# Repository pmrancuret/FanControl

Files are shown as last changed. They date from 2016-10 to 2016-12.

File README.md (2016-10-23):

#Fan Control

*This project is still a work in progress, so the contents are incomplete*

This project contains everything needed to create a Fan Control board.  This board is used to operate two cooling fans to regulate temperature in an enclosed environment.  In our case, it is going to be used to keep a Playstation cool, inside an enclosed cabinet.  The fans are positioned over holes in the back of the cabinet.

Please feel free to contact me with questions, comments, suggestions, or contributions!

## Contents
* [Features and Specifications] (#features)
* [Parts List] (#partslist)
* [Operation Manual] (#operation)
* [Software Load Instructions] (#swload)

# <a name="features"/>Features and Specifications

## Fan Control board is used to power and control two PC fans, independently.

* Works with two standard 3-wire PC fans.
	* Pin 1 is ground.
	* Pin 2 is fan voltage.
	* Pin 3 is hall-effect sensor (for speed feedback).
* May be used with only one fan if desired.
* Continuous current rating of up to 540mA on each fan.
* Combined power rating of two fans is 6 Watts.
	* This power is limited by wall adapter power rating.
	* Using a 12V supply rated at >= 14.2 Watts would allow up to a combined fan power rating of 13 Watts.
* User may specify maximum fan voltage range.
	* Minimum fan voltage >= 3V.
	* Maximum fan voltage <= 12V.
* Speed of each fan is measured independently using hall-effect sensor feedback.
	* Minimum measurable speed of TBD rpm.
	* Maximum measurable speed of TBD rpm.
* Master On/Off switch provided at board input.

## Arduino mini used for control logic.
* An LCD screen and three pushbuttons are provided to allow the user to provide input settings and view status info.
	* Two buttons used as up/down for scrolling through menu items and adjusting values.
	* One button used as an enter key for making selections.
	* Not pressing any button for 10 seconds will return to default display screen.
* A switch is provided to turn backlight LED on/off.  
* Two potentiometers are provided to allow changing brightness and contrast of screen.
* Default display screen shows both fan speeds and both temperature readings in real-time.
* User may select displayed temperature units (C or F).
* User may change proportional and integral gains for each fan speed control loop.
* User may change various speed, voltage, and temperature limits.
* All settings saved in non-volatile EEPROM.
* User may restore all settings to default values.

## Two independent temperature sensors are used for feedback.  
* User can populate these sensors on-board, or use jumper wires to place them remotely.
* User may select whether to use an average or max temperature for determining fan speeds, or control each fan speed independently using respective temperature sensors.
* User may specify up to 8 point pairs each of the two fan speed vs. temperature lookup tables.
	* Min/Max speed values same as min/max measurable speeds listed above.
	* Minimum temperature value of 0 C.
	* Maximum temperature value of 100 C.
	* Sensor accuracy of +/- 2 C.
	* User may specify table settings with resolution of 0.1 C.
	
## Custom designed PCB.
* Dimensions are 3.1" x 3.9".
* Thickness is 0.062".
* Two-layer board, with only through-hole components for easier soldering (depending who you ask).
* Four mounting holes (0.126" drill) provided in corners.
* Refer to [The Eagle Schematic and Board Files] (https://github.com/pmrancuret/FanControl/tree/master/Schematic_and_Board) for board layout and mounting pattern.

## Custom software.
* Refer to (TBD Code Directory) for code.
* Eclipse (TBD version) used to write and compile software.
* Refer to [Software Load Instructions] (#swload) for instructions on building and loading software into the Arduino mini.

# <a name="partslist"/>Parts List

The following parts were used to assemble this board.  Please refer to [The Eagle Schematic and Board Files] (https://github.com/pmrancuret/FanControl/tree/master/Schematic_and_Board) for information about where each component is used.

Prices in table below are as of Aug 13, 2016.  If you are making this, you may choose to get some extras of some components.  The table below only lists the minimum quantity.  Mounting hardware not included.  PC Fans not included.  Tax/shipping not included.  Money could be saved by using a protoboard instead of making the PCB.  But what's the fun in that?

| Description | Manufacturer | Part Number | Quantity | Cost (each) | Cost (total) |
| --- | --- | --- | --- | --- | --- |
| Circuit Board | Pentalogix | [Upload Gerbers] (http://www.pentalogix.com) | 1 | $147.90 | $147.90 |
| Wall Adapter | Sparkfun | [TOL-09442] (https://www.sparkfun.com/products/9442) | 1 | $5.95 | $5.95 |
| Arduino Pro Mini 328 | Sparkfun | [DEV-11113] (https://www.sparkfun.com/products/11113) | 1 | $9.95 | $9.95 |
| LCD Screen | Xiamen Ocular | [GDM1602K] (https://www.sparkfun.com/products/709) | 1 | $15.95 | $15.95 |
| Pushbutton | Sparkfun | [COM-09190] (https://www.sparkfun.com/products/9190) | 3 | $0.50 | $1.50 |
| DC Power Jack | CUI Inc | [PJ-202A] (https://www.sparkfun.com/products/119) | 1 | $1.25 | $1.25 |
| Temperature Sensor | Analog Devices | [TMP37] (http://www.digikey.com/product-detail/en/analog-devices-inc/TMP37FT9Z/TMP37FT9Z-ND/1217626) | 2 | $1.54 | $3.08 |
| Female Break-Away Pin Headers | Sparkfun | [PRT-00115] (https://www.sparkfun.com/products/115) | 1 | $1.50 | $1.50 |
| Male Break-Away Pin headers | Sparkfun | [PRT-00116] (https://www.sparkfun.com/products/116) | 1 | $1.50 | $1.50 |
| 10kOhm, 1/6W, 5% Through-Hole Resistor | Sparkfun | [COM-11508] (https://www.sparkfun.com/products/11508) | 7 | NA | $0.95 |
| 5.1Ohm, 1/4W, 5% Through-Hole Resistor | Yageo | [CFR-25JB-52-5R1] (https://www.digikey.com/product-detail/en/yageo/CFR-25JB-52-5R1/5.1QBK-ND/2238) | 6 | $0.10 | $0.60 |
| 1kOhm, 1/6W, 5% Through-Hole Resistor | Yageo | [CFR-12JB-52-1K] (https://www.digikey.com/product-detail/en/yageo/CFR-12JB-52-1K/1.0KEBK-ND/4000) | 2 | $0.10 | $0.20 |
| 100Ohm, 1/2W Potentiometer | Bourns Inc. | [3362P-1-101LF] (https://www.digikey.com/product-detail/en/bourns-inc/3362P-1-101LF/3362P-101LF-ND/1088410) | 1 | $1.02 | $1.02 |
| 10kOhm, 1/2W Potentiometer | Bourns Inc. | [3362P-1-103LF] (https://www.digikey.com/product-detail/en/bourns-inc/3362P-1-103LF/3362P-103LF-ND/1088412) | 1 | $1.02 | $1.02 |
| 10uF, 25V Through-Hole Ceramic Capacitor | TDK Corporation | [FK16X7R1E106K] (https://www.digikey.com/product-detail/en/tdk-corporation/FK16X7R1E106K/445-8351-ND/2815281) | 7 | $0.63 | $4.41 |
| 1.5mH, 540mA Through-Hole Inductor | Abracon LLC | [AIUR-06-152K] (https://www.digikey.com/product-detail/en/abracon-llc/AIUR-06-152K/AIUR-06-152K-ND/2343620) | 2 | $0.99 | $1.98 |
| P-Channel MOSFET (30V, 650mA) | Microchip Technology | [VP3203N3-G] (https://www.digikey.com/product-detail/en/microchip-technology/VP3203N3-G/VP3203N3-G-ND/4902418) | 2 | $1.37 | $2.74 |
| NPN Transistor (40V, 200mA) | Fairchild Semiconductor | [2N3904BU] (https://www.digikey.com/product-detail/en/fairchild-semiconductor/2N3904BU/2N3904FS-ND/1413) | 2 | $0.18 | $0.36 |
| Shottky Diode (1A) | Fairchild Semiconductor | [1N5817] (https://www.digikey.com/product-detail/en/fairchild-semiconductor/1N5817/1N5817FSCT-ND/1532776) | 2 | $0.43 | $0.86 |
| 5V output DC-DC Converter (2.5W) | Recom Power | [R-78E5.0-0.5] (https://www.digikey.com/product-detail/en/recom-power/R-78E5.0-0.5/945-1648-5-ND/2834904) | 1 | $2.84 | $2.84 |
| Slide Switch | CW Industries | [GF-123-0054] (https://www.digikey.com/product-detail/en/cw-industries/GF-123-0054/CWI333-ND/4089770) | 2 | $0.93 | $1.86 |
| 3-Pin fan connector | TE Connectivity | [640456-3] (https://www.digikey.com/product-detail/en/te-connectivity-amp-connectors/640456-3/A19470-ND/259010) | 2 | $0.13 | $0.26 |
| Total Cost  | | | | | $207.68 |

# <a name="operation"/>Operation Manual

*work in progress*

# <a name="swload"/>Software Load Instructions

*work in progress*

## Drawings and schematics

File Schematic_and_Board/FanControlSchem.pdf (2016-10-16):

# U2ADB0 DB1 DB2 DB3 DB4 DB5 DB6 DB7 EKR/W

A

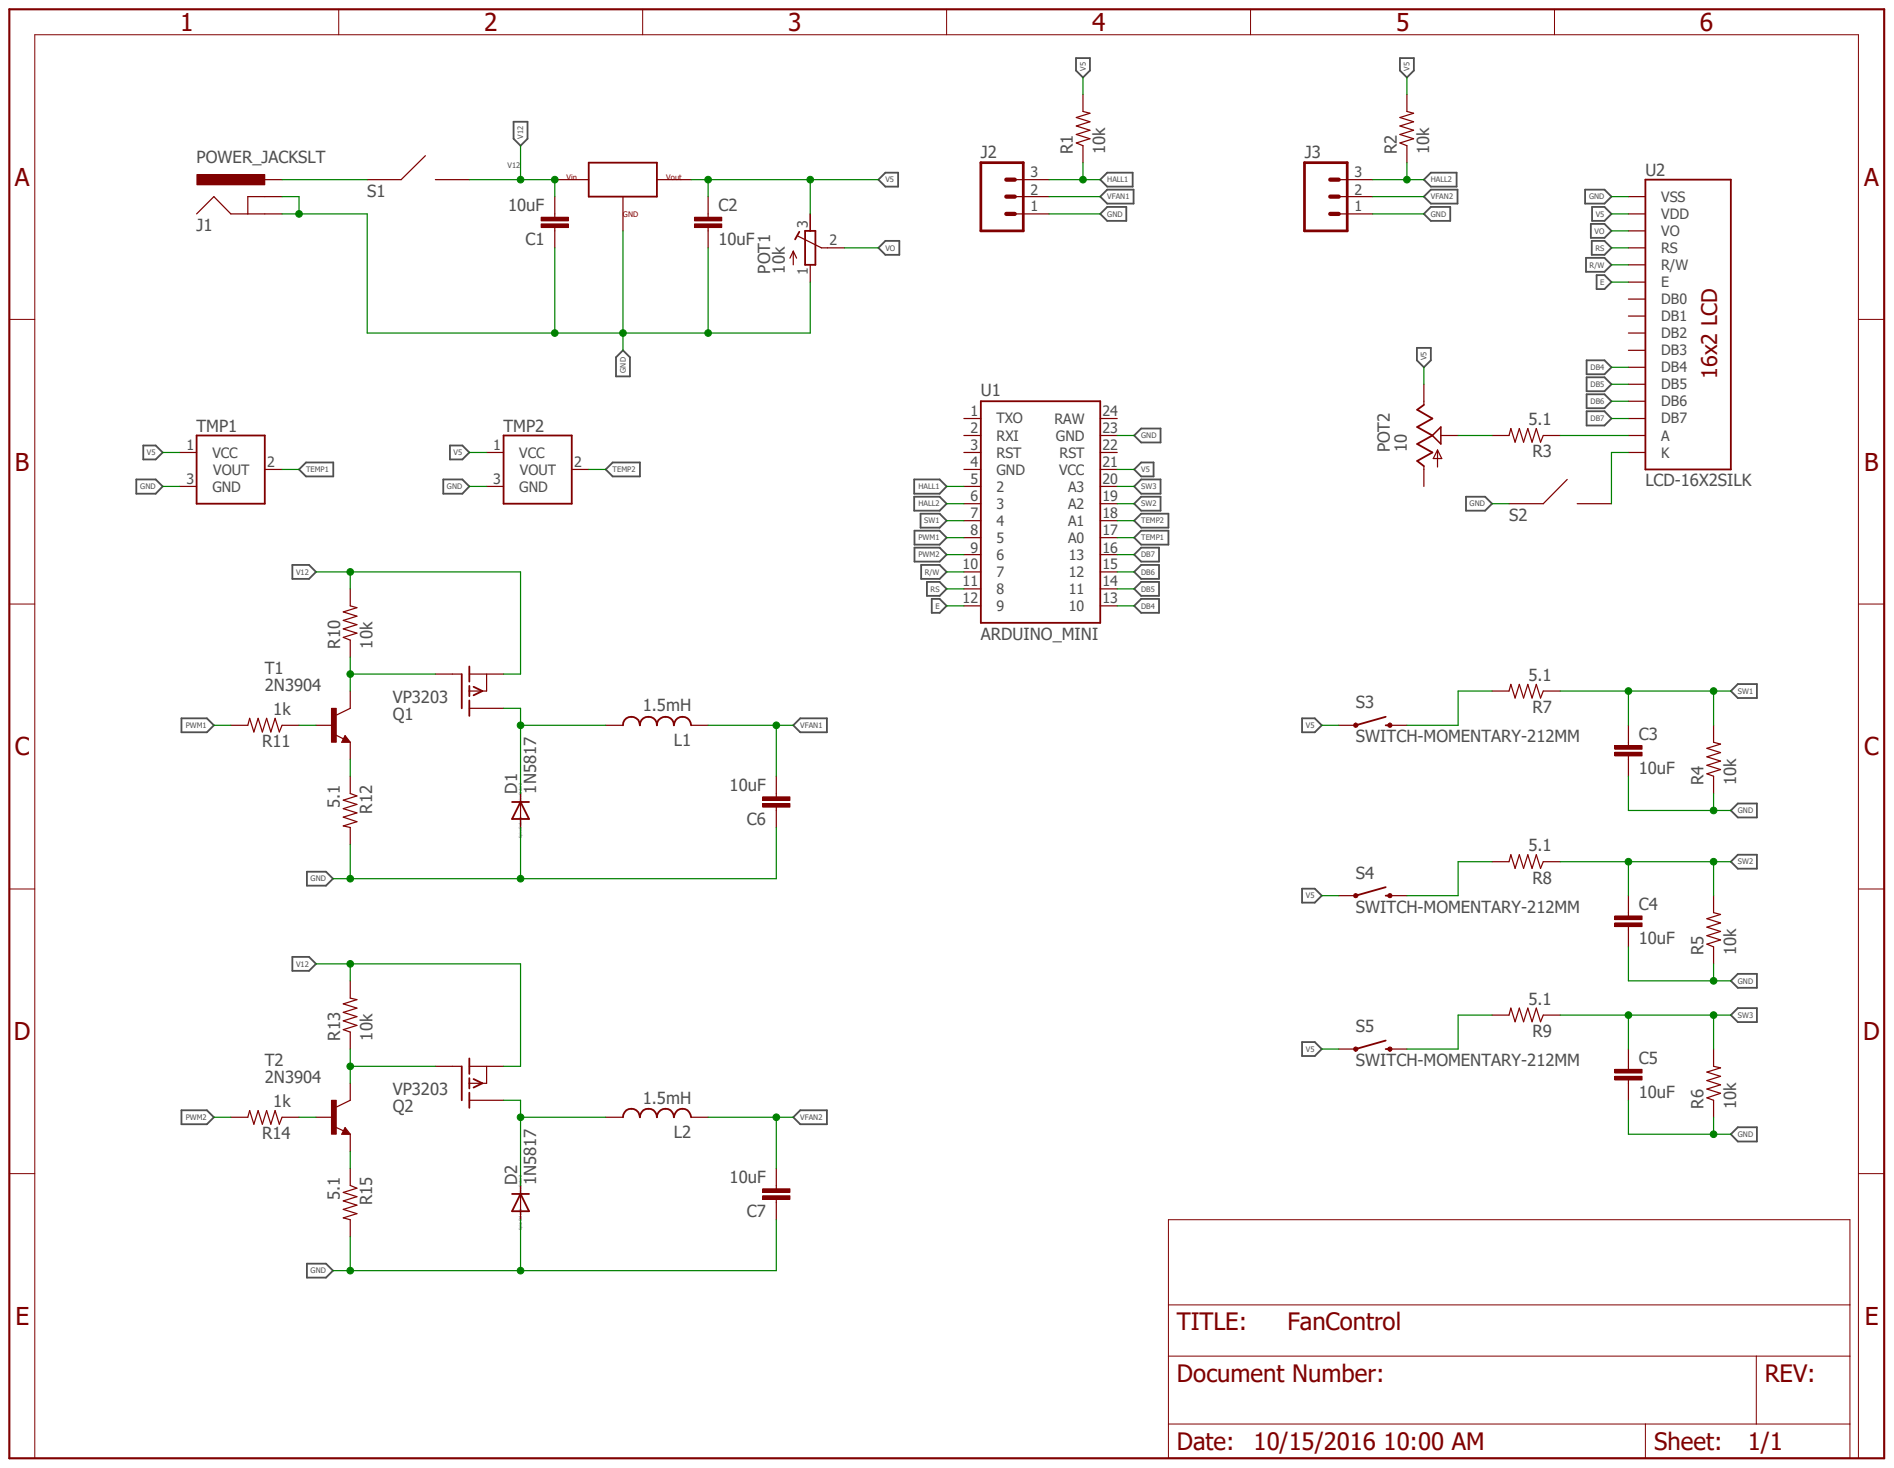
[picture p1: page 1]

SpiceOrder 1 SpiceOrder 2

Document Number: | REV:

Date: 10/15/2016 10:00 AM | Sheet: 1/1

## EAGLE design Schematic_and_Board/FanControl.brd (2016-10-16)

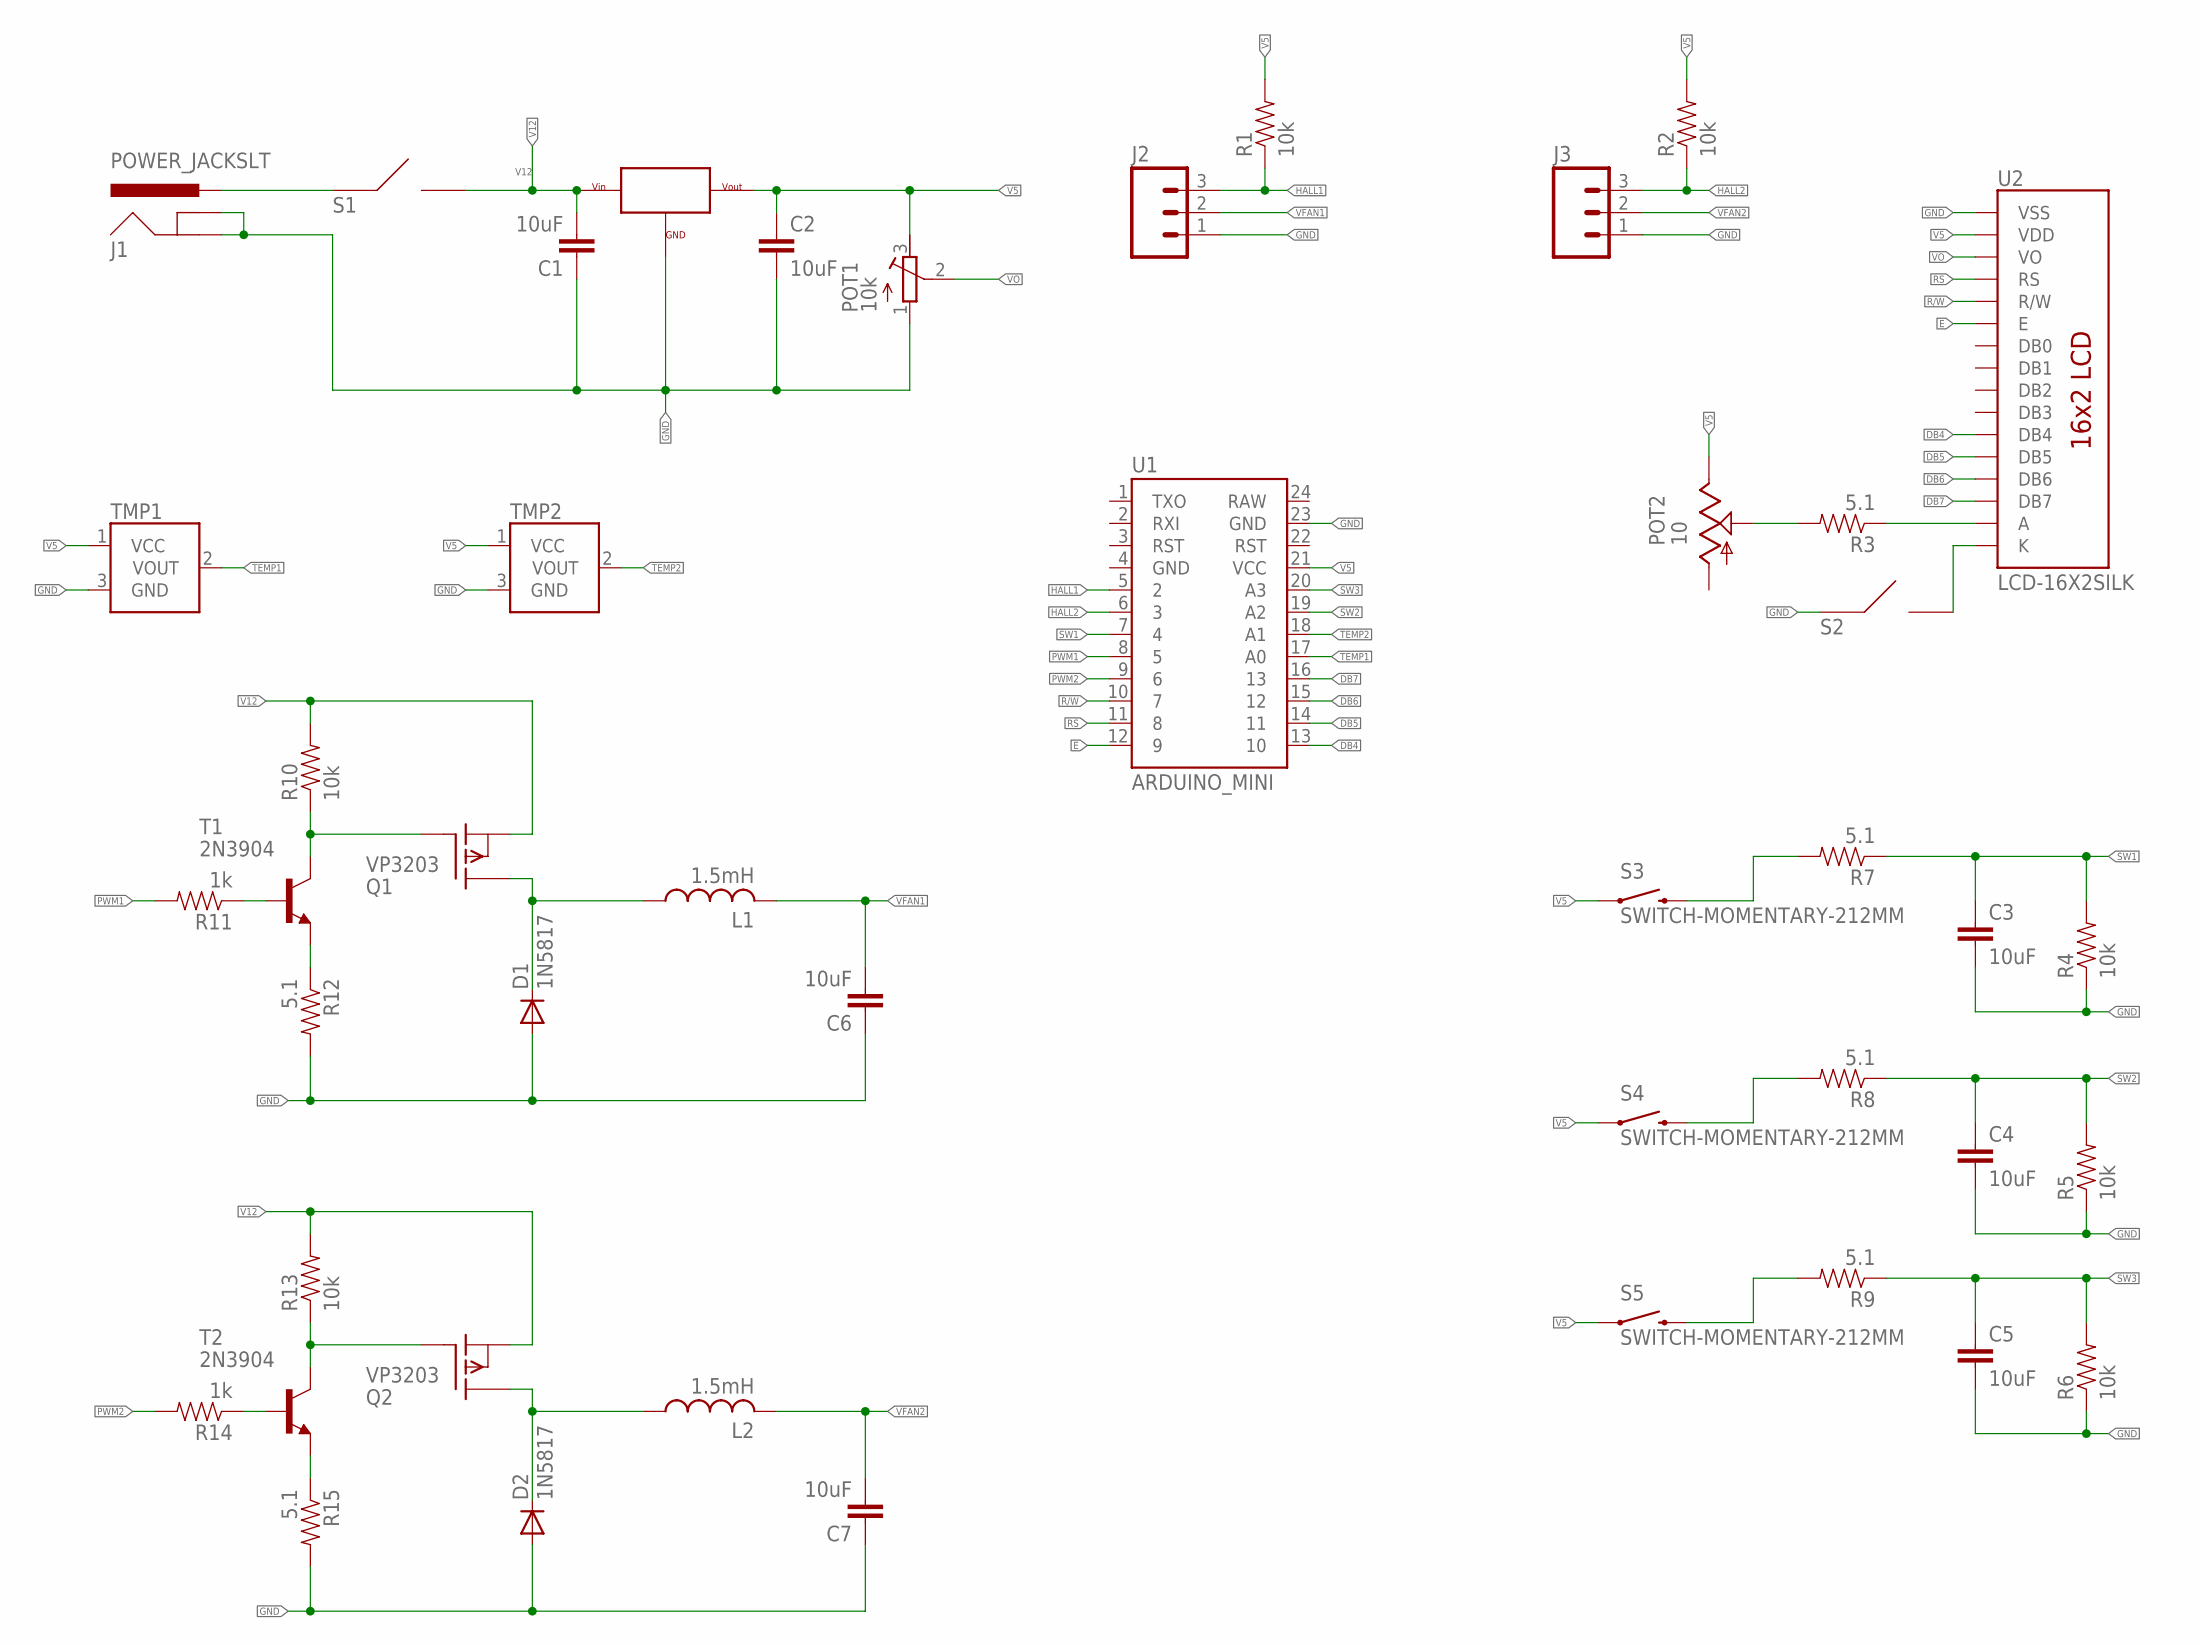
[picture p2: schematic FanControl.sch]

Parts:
C1, C2, C3, C4, C5, C6, C7: 10uF; CAP-PTH-5MM
D1, D2: 1N5817; DO41-10
J1: POWER_JACKSLT; POWER_JACK_SLOT
J2, J3: M03POLAR; MOLEX-1X3
L1, L2: 1.5mH; 0204/7
POT1: 10k; RTRIM3362P
POT2: 10; B25P
Q1, Q2: VP3203; TO-92
R1, R2, R4, R5, R6, R10, R13: 10k; 1/6W-RES
R3, R7, R8, R9, R12, R15: 5.1; 1/6W-RES
R11, R14: 1k; 1/6W-RES
S1, S2: SLIDE_SWITCH; TH_SLIDE_SWITCH
S3, S4, S5: SWITCH-MOMENTARY-212MM; TACTILE-PTH-12MM
T1, T2: 2N3904; TO92
TMP1, TMP2: TMP36GT9; TO-92
U1: ARDUINO_MINI
U2: LCD-16X2SILK; LCD-16X2
U$1: R-78EXX-0.5

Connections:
DB4: U1.13 (10), U2.11 (DB4)
DB5: U1.14 (11), U2.12 (DB5)
DB6: U1.15 (12), U2.13 (DB6)
DB7: U1.16 (13), U2.14 (DB7)
E: U1.12 (9), U2.6 (E)
GND: C1.1, C2.2, C3.2, C4.2, C5.2, C6.1, C7.1, D1.A, D2.A, J1.GND@1 (GNDBREAK), J1.GND@2 (GND), J2.1, J3.1, POT1.1, R4.1, R5.1, R6.1, R12.2, R15.2, S2.A, TMP1.3 (GND), TMP2.3 (GND), U1.23 (GND), U2.1 (VSS), U$1.GND
HALL1: J2.3, R1.1, U1.5 (2)
HALL2: J3.3, R2.1, U1.6 (3)
unnamed: POT2.S, R3.2
unnamed: R3.1, U2.15 (A)
unnamed: J1.PWR, S1.A
unnamed: S2.B, U2.16 (K)
unnamed: R7.2, S3.3 (2)
unnamed: R8.2, S4.3 (2)
unnamed: R9.2, S5.3 (2)
unnamed: R12.1, T1.3 (E)
unnamed: Q1.2 (G), R10.1, T1.1 (C)
unnamed: R11.1, T1.2 (B)
unnamed: D1.C, L1.1, Q1.3 (D)
unnamed: Q2.2 (G), R13.1, T2.1 (C)
unnamed: R14.1, T2.2 (B)
unnamed: R15.1, T2.3 (E)
unnamed: D2.C, L2.1, Q2.3 (D)
PWM1: R11.2, U1.8 (5)
PWM2: R14.2, U1.9 (6)
R/W: U1.10 (7), U2.5 (R/W)
RS: U1.11 (8), U2.4 (RS)
SW1: C3.1, R4.2, R7.1, U1.7 (4)
SW2: C4.1, R5.2, R8.1, U1.19 (A2)
SW3: C5.1, R6.2, R9.1, U1.20 (A3)
TEMP1: TMP1.2 (VOUT), U1.17 (A0)
TEMP2: TMP2.2 (VOUT), U1.18 (A1)
V5: C2.1, POT1.3, POT2.E, R1.2, R2.2, S3.1, S4.1, S5.1, TMP1.1 (VCC), TMP2.1 (VCC), U1.21 (VCC), U2.2 (VDD), U$1.VOUT
V12: C1.2, Q1.1 (S), Q2.1 (S), R10.2, R13.2, S1.B, U$1.VIN
VFAN1: C6.2, J2.2, L1.2
VFAN2: C7.2, J3.2, L2.2
VO: POT1.2, U2.3 (VO)

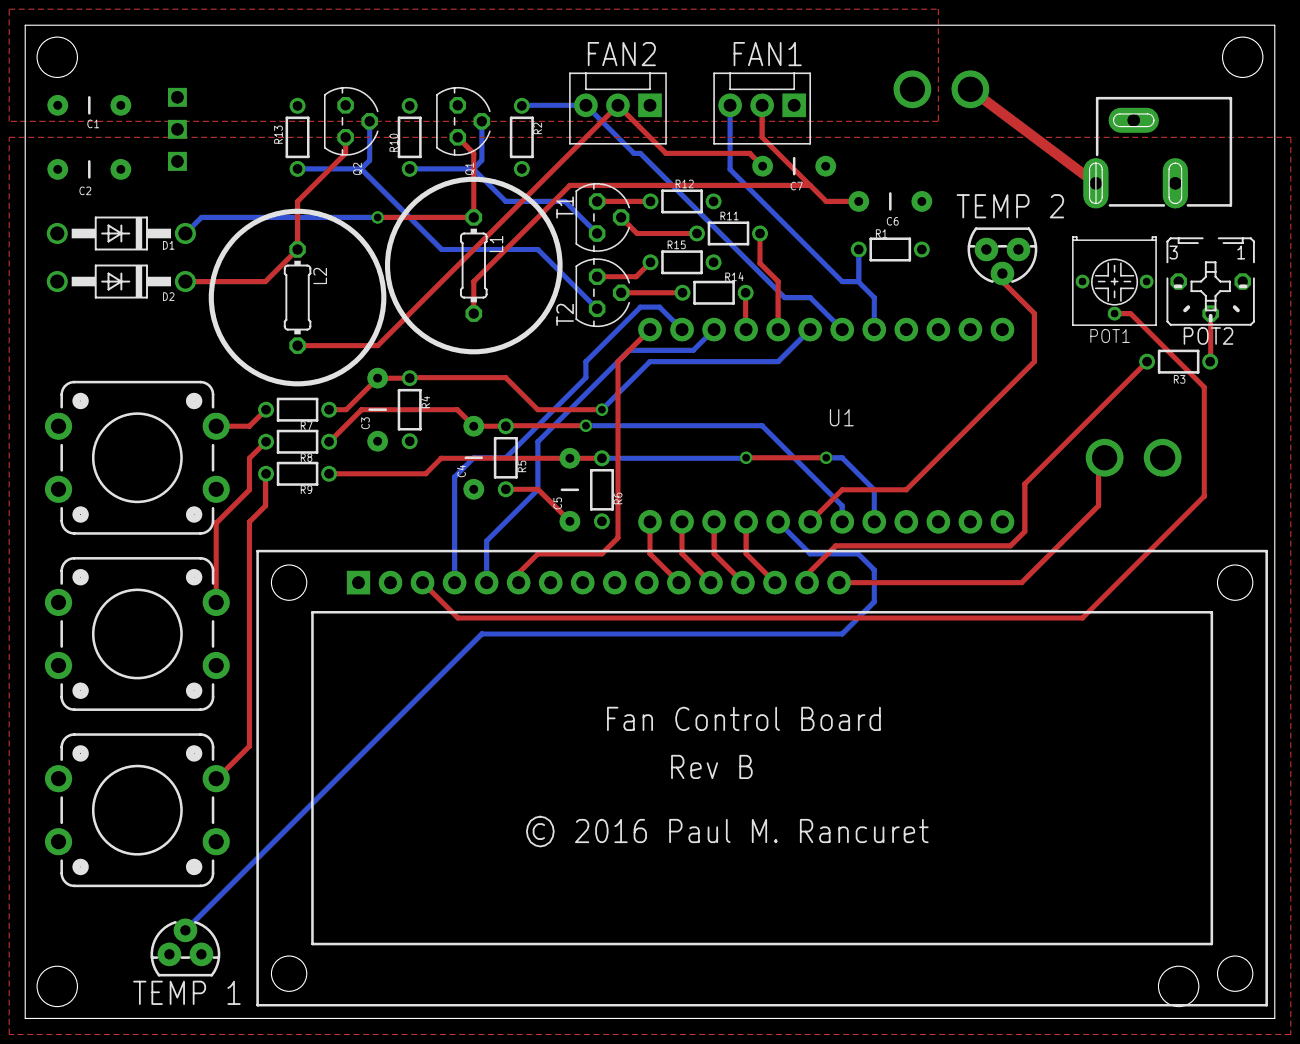
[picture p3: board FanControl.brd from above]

Board: 2 copper layers, 99.1 x 78.7 mm, 45 parts (0 on the bottom side), 37 nets.

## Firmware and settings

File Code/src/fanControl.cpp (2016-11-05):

/*******************************************************************************
 * INCLUDE HEADERS
 ******************************************************************************/
#include "FanControl.h"

fanCtrlStateMachine stateMachine; // define the state machine

/*******************************************************************************
 * FUNCTION DEFINITIONS
 ******************************************************************************/

/******************************************************************************
* Function:
*   setup()
*
* Description:
*   Initialization routines performed upon boot-up of the device.
*
* Arguments:
*   none
*
* Returns:
*   none
******************************************************************************/
void setup ( void )
{
  /* Reset state machine, which will initialize the system */
  stateMachine.reset ( );

  return; // end of setup()
}         // end of setup()

/******************************************************************************
* Function:
*   loop()
*
* Description:
*   This is the main loop of the program.  It runs endlessly after
*   initialization is complete.
*
* Arguments:
*   none
*
* Returns:
*   none
******************************************************************************/
void loop ( void )
{
  static unsigned long lastTime = 0;          // time when last loop began (microseconds/64)
  unsigned long        thisTime = micros ( ); // time now (in microseconds/64)

  /* Check to see if it is time to run a new loop, otherwise return */
  if ( thisTime - lastTime >= LOOPTIME_US * 64 ) // enough time elapsed for new loop
    lastTime = thisTime;                         // store loop time for next iteration
  else
    return; // skip this loop iteration

  /* keep track of total program run time */
  runTime_s = loopsRun * LOOPTIME_US / 1000000; // track runtime in seconds
  loopsRun++;                                   // increment count of loops run

  /* Calculate Fan speeds in RPM */
  measFanSpeeds ( thisTime );

  /* Read temperature measurements */
  Temp1 = analogRead ( TEMP1PIN ); // read temp sensor 1
  Temp2 = analogRead ( TEMP2PIN ); // read temp sensor 2

  /* Check for button clicks and update consecutive button press count */
  checkButtonPress ( );

  /* Run state machine */
  stateMachine.run ( );

  /* Set duty cycle for pwm outputs */
  analogWrite ( PWM1PIN, Pwm1Duty ); // set pwm1 duty
  analogWrite ( PWM2PIN, Pwm2Duty ); // set pwm2 duty

  return; // end of loop()
}         // end of loop()

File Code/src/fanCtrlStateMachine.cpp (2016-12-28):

/*
 * fanCtrlStateMachine.cpp
 *
 *  Created on: Nov 4, 2016
 *      Author: Paul
 */


#include "fanCtrlStateMachine.h"
#include "FanControlUtils.h"
#include "LiquidCrystal.h"
#include "savedVars.h"
#include "piController.h"

/* Declare the class objects, which are defined elsewhere */
extern LiquidCrystal lcd;
extern piController  pi1;
extern piController  pi2;

/*******************************************************************************
 * FUNCTION DEFINITIONS
 ******************************************************************************/

/******************************************************************************
* Function:
*   checkDebugMsgs()
*
* Description:
*   Checks serial input for commands to enter a debug mode.  If no message is
*   received, and there is no debug timeout, it will remain in same state.  If
*   already in debug mode, and a debug timeout occurs, it will return to normal
*   state.
*
* Arguments:
*   none
*
* Returns:
*   nextState - state to enter on next loop.
******************************************************************************/
static FANCTRLSTATE_ENUM_TYPE checkDebugMsgs ( FANCTRLSTATE_ENUM_TYPE thisState )
{
  FANCTRLSTATE_ENUM_TYPE nextState = thisState;                   // By default, remain in same state
  int                    cnt;                                     // count variable used for loop
  byte                   readBuffer [ DEBUGBUFFSIZE ];            // buffer for storing serial input
  int                    serialBytesAvail = Serial.available ( ); // number of bytes available to read
  int                    bytesRead;                               // number of bytes read
  static int             numDebugLoops;                           // number of consecutive loops in same debug mode without getting new message
  char                   msgHeader [ DEBUGHEADSIZE + 1 ];         // string containing message header read

  /* Make sure we don't read more bytes than our buffer can store */
  if ( serialBytesAvail > DEBUGBUFFSIZE )
    serialBytesAvail = DEBUGBUFFSIZE;

  /* Put terminator character at end of header buffer */
  msgHeader [ DEBUGHEADSIZE ] = '\0';

  /* Read serial data if enough bytes are available */
  if ( serialBytesAvail >= ( DEBUGMSG_DATWORDS * 2 + DEBUGHEADSIZE ) )
  {
    bytesRead = Serial.readBytes ( readBuffer, serialBytesAvail ); // read until all data is read, or buffer is full

    for ( cnt = 0;
      cnt <= ( bytesRead - ( DEBUGMSG_DATWORDS * 2 + DEBUGHEADSIZE ) );
      cnt++ ) // loop through each character of buffer which could potentially be the start of a debug message command.  Must have sufficient bytes to the right.
    {
      memcpy ( msgHeader, readBuffer + cnt, DEBUGHEADSIZE ); // copy header from read buffer into header string buffer

      /* Compare header with valid headers to see if a valid debug mode was specified */
      if ( strcmp ( msgHeader, NORMAL_HEAD ) == 0 )
      {
        nextState = NORMAL; // set next state to return to normal
        break;              // exit loop, don't load debug message data
      }
      else if ( strcmp ( msgHeader, DEBUGPI1_HEAD ) == 0 )
        nextState = DEBUG_PI1; // set next state to requested debug state
      else if ( strcmp ( msgHeader, DEBUGPI2_HEAD ) == 0 )
        nextState = DEBUG_PI2; // set next state to requested debug state
      else if ( strcmp ( msgHeader, DEBUGBTN_HEAD ) == 0 )
        nextState = DEBUG_BTNS; // set next state to requested debug state
      else if ( strcmp ( msgHeader, DEBUGTMP_HEAD ) == 0 )
        nextState = DEBUG_TMP; // set next state to requested debug state
      else if ( strcmp ( msgHeader, DEBUGFON_HEAD ) == 0 )
        nextState = DEBUG_FON; // set next state to requested debug state
      else if ( strcmp ( msgHeader, DEBUGTB1_HEAD ) == 0 )
        nextState = DEBUG_TB1; // set next state to requested debug state
      else if ( strcmp ( msgHeader, DEBUGTB2_HEAD ) == 0 )
        nextState = DEBUG_TB2; // set next state to requested debug state
      else
        continue; // did not find valid message, skip to next buffer value

      /* If we made it to this point, a valid debug message was found */
      memcpy ( debugDatWords, readBuffer + cnt + DEBUGHEADSIZE, DEBUGMSG_DATWORDS * 2 ); // copy data payload into debug words buffer
      numDebugLoops = 0;                                                                 // reset counter of consecutive debug loops without getting new message

      break; // exit loop, since we found the valid message
    }
  }

  /* Check number of consecutive debug loops, and exit to normal mode if timeout occurred */
  if ( nextState == DEBUG_PI1 ||
    nextState == DEBUG_PI2 ||
    nextState == DEBUG_BTNS ||
    nextState == DEBUG_TMP ||
    nextState == DEBUG_FON ||
    nextState == DEBUG_TB1 ||
    nextState == DEBUG_TB2 ) // if we are in (or entering) debug state
  {
    if ( numDebugLoops++ >= DEBUG_TIMEOUT ) // increment count of debug loops, and check for timeout
    {
      numDebugLoops = 0;      // reset debug loop counter
      nextState     = NORMAL; // exit debug mode, go back to normal state
    }
  }

  return nextState;
} // end of checkDebugMsgs();
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

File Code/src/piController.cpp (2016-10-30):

/*
 * piController.cpp
 *
 *  Created on: Oct 29, 2016
 *      Author: Paul
 */


#include "piController.h"


/*******************************************************************************
 * FUNCTION DEFINITIONS
 ******************************************************************************/


/******************************************************************************
* Function:
*   piController()
*
* Description:
*   Constructor function for a piController object
*
* Arguments:
*   sampleTimeSet - sets sample time (microseconds)
*   maxErrIntSet - sets max integrator value (tenths of error count times seconds)
*   minErrIntSet - sets min integrator value (tenths of error count times seconds)
*   kpSet - sets proportional gain (2^-13 duty counts per error count)
*   kiSet - sets integral gain (2^-17 duty counts per error count per 100 milliseconds)
*
* Returns:
*   none
******************************************************************************/
piController :: piController ( unsigned long sampleTimeSet, int maxErrIntSet, int minErrIntSet, int kpSet, int kiSet )
{
  sampleTime  = sampleTimeSet; // set sample time (microseconds)
  errIntegral = 0;             // integral of error (tenths of error count times seconds)
  maxErrInt   = maxErrIntSet;  // maximum value of errIntegral (tenths of error count times seconds)
  minErrInt   = minErrIntSet;  // maximum value of errIntegral (tenths of error count times seconds)
  kp          = kpSet;         // Proportional gain (2^-13 duty counts per error count)
  ki          = kiSet;         // Integral gain (2^-17 duty counts per error count per 100 milliseconds)
  IntTerm     = 0;             // start with integral term = 0
  PropTerm    = 0;             // start with proportional term = 0

  return; // exit function
}         // end of piController()

/******************************************************************************
* Function:
*   setGains()
*
* Description:
*   Updates gains in the piController object
*
* Arguments:
*   sampleTimeSet - sets sample time (microseconds)
*   maxErrIntSet - sets max integrator value (tenths of error count times seconds)
*   minErrIntSet - sets min integrator value (tenths of error count times seconds)
*   kpSet - sets proportional gain (2^-13 duty counts per error count)
*   kiSet - sets integral gain (2^-17 duty counts per error count per 100 milliseconds)
*
* Returns:
*   none
******************************************************************************/
void piController :: setGains ( unsigned long sampleTimeSet, int maxErrIntSet, int minErrIntSet, int kpSet, int kiSet )
{
  sampleTime = sampleTimeSet; // set sample time (microseconds)
  maxErrInt  = maxErrIntSet;  // maximum value of errIntegral (tenths of error count times seconds)
  minErrInt  = minErrIntSet;  // maximum value of errIntegral (tenths of error count times seconds)
  kp         = kpSet;         // Proportional gain (2^-13 duty counts per error count)
  ki         = kiSet;         // Integral gain (2^-17 duty counts per error count per 100 milliseconds)

  return; // exit function
}         // end of setGains()


/******************************************************************************
* Function:
*   resetInt()
*
* Description:
*   Resets integrator to zero
*
* Arguments:
*   none
*
* Returns:
*   none
******************************************************************************/
void piController :: resetInt ( void )
{
  errIntegral = 0; // set integrator to zero (tenths of error count times seconds)

  return; // exit function
}         // end of resetInt()

/******************************************************************************
* Function:
*   resetInt()
*
* Description:
*   Resets integrator to specified value
*
* Arguments:
*   errInt - value to set integrator to (tenths of error count times seconds)
*
* Returns:
*   none
******************************************************************************/
void piController :: resetInt ( int errInt )
{
  errIntegral = errInt; // set integrator to specified value (tenths of error count times seconds)

  return; // exit function
}         // end of resetInt()

/******************************************************************************
* Function:
*   piControl()
*
* Description:
*   Executes PI control step
*
* Arguments:
*   errVal - error term input to PI
*
* Returns:
*   none
******************************************************************************/
byte piController :: piControl ( int errVal )
{
  byte dutyOut; // output duty

  errIntegral = (int) constrain (
    ( ( (long int) errIntegral ) + ( ( ( (long int) errVal ) * (long int) sampleTime ) / 100000L ) ), // add to integrator, which holds error in tenths of rpm times seconds
    ( (long int) minErrInt ), ( (long int) maxErrInt ) );                                             // constrain to stay within integrator limits

  PropTerm = (int) constrain ( ( (long) errVal * kp ) >> 11, -16384, 16383 );      // proportional term, in quarter of duty counts
  IntTerm  = (int) constrain ( ( (long) errIntegral * ki ) >> 15, -16384, 16383 ); // integral term, in quarter of duty counts

  dutyOut  = (byte) constrain ( ( PropTerm + IntTerm ) >> 2, MINPIOUTPUT, MAXPIOUTPUT ); // set output duty

  return dutyOut; // exit function
}                 // end of piControl()


/******************************************************************************
* Function:
*   piControlIntOff()
*
* Description:
*   Executes PI control step without updating integrator.  This can be useful
*   to avoid anti-windup.  It does not set integrator term to zero, it just
*   neglects to update the integral of error.
*
* Arguments:
*   errVal - error term input to PI
*
* Returns:
*   none
******************************************************************************/
byte piController :: piControlIntOff ( int errVal )
{
  byte dutyOut; // output duty

  PropTerm = (int) constrain ( ( (long) errVal * kp ) >> 11, -16384, 16383 );      // proportional term, in quarter of duty counts
  IntTerm  = (int) constrain ( ( (long) errIntegral * ki ) >> 15, -16384, 16383 ); // integral term, in quarter of duty counts

  dutyOut  = (byte) constrain ( ( PropTerm + IntTerm ) >> 2, MINPIOUTPUT, MAXPIOUTPUT ); // set output duty

  return dutyOut; // exit function
}                 // end of piControlIntOff()


/******************************************************************************
* Function:
*   getPropTerm()
*
* Description:
*   returns the proportional term.  good for debugging.
*
* Arguments:
*   none
*
* Returns:
*   PropTerm - proportional term, in quarters of duty count
******************************************************************************/
int piController :: getPropTerm ( void )
{
  return PropTerm;
} // end of getPropTerm()
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

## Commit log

2016-08-13 Add initial schematic, board layout, and gerber files
    [FanControl.brd, FanControl.sch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]
2016-08-13 Update git to ignore eagle back-saved files, and job files. Remove those files from the repository, along with the redundant zip file of gerbers.
2016-09-24 Switch to the built-in Arduino LCD library
2016-10-15 Update Schematic and Board to correct these two errors:
    [FanControl.brd, FanControl.sch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]
2016-10-16 Update board to revision B. This revision corrects the two errors which were present in Rev A. The first error was that the power jack input ground connection was only made to one of the ground pins 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
    [FanControl.brd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]
2016-10-16 Add pdf version of Rev B schematic.
2016-10-16 Improve loop timing by sampling timer values at start of loop, rather than using a delay in the loop. Add functionality to read hall-effect sensors and calculate fan speeds in RPM. Add a run-time cou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
2016-10-16 Add temperature measurement functionality.
2016-10-17 Add volatile keyword to variables used by ISR. Correct min fan speed so it shows zero when below minimum value.
    [fanControl.cpp]
2016-10-17 Correct overflow problems with temperature scaling. Update temperature and speed display screen to look nicer.
    [fanControl.cpp]
2016-10-23 Update README with up-to-date parts list. Changed the temperature sensor part and the potentiometer used for adjusting screen brightness. Modify .gitignore file to ignore eagle.epf file.
2016-10-23 Update default temp sensor scale/offset values to correspond to the TMP37 sensor from analog devices.
2016-10-29 Add ability to load/save variable values from/to EEPROM. Table of variables in savedVars.h file lists these variables, default values, min/max values, byte size, etc. From this table, these variables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
    [fanControl.cpp, savedVars.h]
2016-10-30 Add PI Control functionality to regulate fan speeds.
2016-11-05 Add reset function for state machine. Add button press reading functionality.
    [fanControl.cpp, fanCtrlStateMachine.cpp]
2016-11-05 Rename FanControlUtils to lower-case fanControlUtils for consistency.
2016-11-05 Add debug modes for PI1, PI2, and button presses.
2016-11-05 Adjust LCD screen alignment in button debug mode.
2016-11-05 Increase debug timeout value. correct second line screen printing format in button press debug mode.
    [fanControlUtils.h, fanCtrlStateMachine.cpp]
2016-11-05 Change debug PI modes to turn off other fan when debugging one.
2016-11-05 Correct byte order for PI debug modes, and add ability to specify min/max rpm commands.
    [fanCtrlStateMachine.cpp]
2016-11-05 Add temp sensor debug mode.
2016-11-06 Add fan speed vs temperature curves for both fans. Add ability to select temperature reading source for each fan (tmp1, tmp2, max, mean). Add interpolation functionality so that fan reference speeds 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
    [fanControlUtils.cpp, savedVars.h]
2016-11-06 Add debug state for controlling fan turn-on and turn-off.
2016-11-06 Add debug modes for configuring fan temp-speed lookup tables 1 and 2
2016-11-06 Correct error with displaying table temps 3&4 in lookup table debug modes.
    [fanCtrlStateMachine.cpp]

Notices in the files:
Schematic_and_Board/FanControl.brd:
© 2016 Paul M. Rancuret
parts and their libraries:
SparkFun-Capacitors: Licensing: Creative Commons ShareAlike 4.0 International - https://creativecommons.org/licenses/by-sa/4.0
